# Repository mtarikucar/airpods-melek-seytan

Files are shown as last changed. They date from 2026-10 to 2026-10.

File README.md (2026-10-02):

# AirPods melek ve şeytan

Kulaklık sapına geçen melek (sağ kulaklık) ve şeytan (sol kulaklık) figürleri. Dört kulaklık grubu için basılabilir STL dosyaları **[out/](out/OKU_BENI.md)** klasöründedir: AirPods 4/5, AirPods Pro 3, AirPods Pro 2 ve AirPods 2/1.

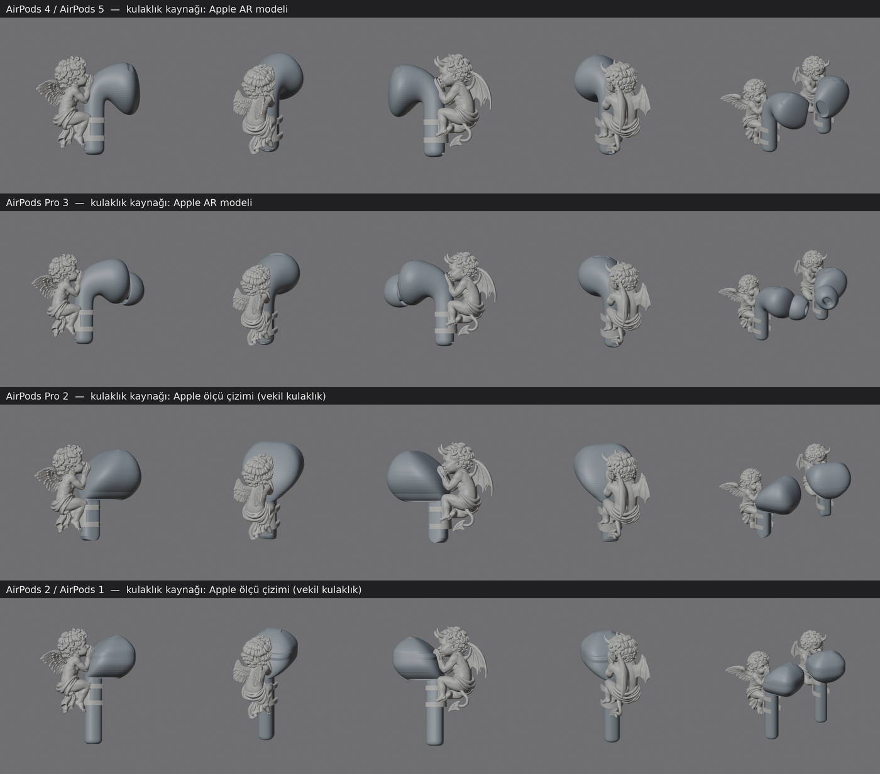
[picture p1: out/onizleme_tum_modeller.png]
Tüm modeller


Baskı, geçme testi ve kullanım uyarıları [out/OKU_BENI.md](out/OKU_BENI.md) dosyasındadır.

## Site ilanı

Ürün sayfası için görseller ve Türkçe metin **[out/ilan/](out/ilan/ILAN_METNI.md)** klasöründedir: `gorseller/` altında 11 JPG (melek beyaz, şeytan kırmızı), `ILAN_METNI.md` içinde ürün adı, açıklamalar, SSS, SEO alanları ve alt metinler.

Görseller satışa hazır STL'lerden Cycles ile çizilen render'lardır, fotoğraf değildir. Yeniden üretmek için:

1. `blender -b --factory-startup --python scripts/ilan_render.py` (ham render'lar `work/ilan/` altına; `--preview` hızlı ve küçük, `--shots ana,melek` tek tek çizer)
2. `.venv/bin/python scripts/ilan_etiket.py` (yazıları ve ölçü çizgilerini ekler, `out/ilan/gorseller/` altına JPG yazar)

Renkler `ilan_render.py` başındaki `MELEK_COL` ve `SEYTAN_COL` değerleridir.

## Tanıtım videoları

**[videolar/](videolar/)** klasöründe iki tanıtım videosu, her biri 4K ve 1080p olarak:

| Dosya | Çözünürlük | Süre |
|---|---|---|
| `urun_videosu_dikey_4k.mp4` | 2160×3840 (dikey) | 8 sn |
| `urun_videosu_dikey_1080p.mp4` | 1080×1920 (dikey) | 8 sn |
| `kisa_film_4k.mp4` | 3840×2160 | 24 sn |
| `kisa_film_1080p.mp4` | 1920×1080 | 24 sn |

Videolar yapay zekâ ile üretildi (Seedance 2.5, 480p/612p taslak), sonra SeedVR2 7B ile yerelde 1080p ve 4K'ya büyütüldü. `kisa_film_4k.mp4` GitHub'ın 100 MB dosya sınırına sığması için daha düşük bit hızıyla kodlandı.

## Kaynaklar

- `references/`: kullanıcının verdiği konsept görselleri. Figürler `kaynak_figurler.png` görselinden kırpılan `melek.png` ve `seytan.png` ile üretildi.
- Figürler Meshy image-to-3d ile üretildi (meshy-7.1, 4k geometri, doku yok). İki üretim toplam 50 kredi harcadı; kalan bakiye 2385. API anahtarı hiçbir dosyaya yazılmadı, yalnızca `MESHY_API_KEY` ortam değişkeninden okunur.
- Kulaklık geometrisi:
  - AirPods 5 (4 ile aynı gövde) ve Pro 3: apple.com ürün sayfalarındaki AR (USDZ) modeller.
  - Pro 2 ve AirPods 2: developer.apple.com/accessories/dimensional-drawings çizimleri.
  
  Ham dosyalar `raw/` altında yerelde tutulur.

## Yeniden üretim

Kurulum: `python -m venv .venv && .venv/bin/pip install -r requirements.txt`. Blender 5.2 kullanıldı.

1. `python scripts/crop_refs.py`: kaynak görselden figürleri kırpar.
2. `MESHY_API_KEY=... python scripts/meshy.py submit melek seytan` ve `... wait melek seytan`: üretir ve `raw/<figür>/` altına indirir.
3. `blender -b --python scripts/solidify_figure.py -- raw/<figür>/stl.stl work/<figür>_solid.stl`, ardından `python scripts/decimate.py work/<figür>_solid.stl work/<figür>_600k.stl 600000`: figürü 30 mm, kapalı katı yapar.
4. Kulaklıkları hazırlar:
   - `blender -b --python scripts/extract_earbud.py -- raw/airpods5.usdz earbuds/airpods45` (aynısı `airpodspro3.usdz` için de), ardından `decimate.py ... earbuds/<ad>_{L,R}_dec.stl 250000`.
   - `python scripts/make_proxy.py`: Pro 2 ve AirPods 2'yi çizimlerden kurar. Sonra `scripts/voxel_clean.py` ve `decimate.py` çalıştırılır.
5. `scripts/run_all.sh`: dört modeli üretir (`build.py`), kuponları çıkarır (`coupons.py`), et kalınlığını ölçer (`check_thickness.py`), paketi ve önizlemeleri hazırlar (`package.py`).

## Geçme tasarımı (`scripts/build.py`)

- Kişi -Y yönüne bakar, +Z yukarıdır. Sağ kulaklık -X tarafındadır.
- Figür sapın arkasına (+Y) yerleşir, dizleri sapa 2,5 mm gömülür, 1,5 mm dışa kaydırılır.
- Figürden, kulaklığın önden arkaya takılırken süpürdüğü hacim çıkarılır; bu yüzden takmayı engelleyen alttan kesik kalmaz.
- Kulaklık ile figür arasında yan başına 0,12 mm boşluk vardır.
- Diz ve ayak hizasında 1,8 mm yüksek, 1,1 mm kalın iki C kelepçe vardır. Ağızları sapın X genişliğinin %84'üdür.
- Sapın arkasındaki 1,0 mm şerit kelepçeleri figüre bağlar.
- Ellerin altında, kulaklık başına 1,0 mm oturan avuç yastığı vardır. Bu yastık ellerin dışbükey zarfıyla sınırlıdır.
- Başa bakan kanat kesilir.
- Dışa aktarmada aynı konumdaki köşeler birleştirilir ve 0,002 mm altı kıymıklar temizlenir (`fitlib.clean_export`).

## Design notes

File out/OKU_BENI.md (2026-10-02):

# AirPods melek ve şeytan figürleri

Melek **sağ**, şeytan **sol** kulaklığa takılır. Figür sapın arka tarafından yukarı tırmanmış durur, ellerini kulaklığın başına dayar. Sapı diz ve ayak hizasındaki iki C kelepçe sarar; avuçlar kulaklık başının arka yüzüne oturur. Figür kulaklığa arkadan, ileri doğru bastırılarak takılır; kelepçeler sapın üzerinden esneyip geçerek oturacak şekilde tasarlandı.

Tüm modeller

## Modeller

| Klasör | Uyduğu kulaklık | Figür boyu | Ağırlık (1,15 g/cm³) | Kulaklık geometrisinin kaynağı |
|---|---|---|---|---|
| `airpods45/` | AirPods 4, AirPods 5 | 30 mm | melek 1,67 g, şeytan 1,85 g | Apple'ın AR modeli (gerçek ölçekli 3B) |
| `airpodspro3/` | AirPods Pro 3 | 30 mm | 1,67 g / 1,86 g | Apple'ın AR modeli |
| `airpodspro2/` | AirPods Pro 2 (Lightning ve USB-C) | 30 mm | 1,67 g / 1,85 g | Apple ölçü çizimi, vekil kulaklık |
| `airpods2/` | AirPods 2, AirPods 1 | 32 mm | 2,01 g / 2,23 g | Apple ölçü çizimi, vekil kulaklık |

Apple'ın çizimine göre AirPods 4 ve AirPods 5'in gövdesi aynıdır. AirPods 3'ün gövdesi farklı olduğu için pakette yoktur, istenirse eklenir. Taklit AirPods'ların ölçüleri değiştiği için onlara uyum garanti değildir.

## Dosyalar (her model klasöründe)

- `baski/melek_sag.stl`, `baski/seytan_sol.stl`: basılacak figürler. Tablanın ortasında, en alt noktası Z=0'da, takıldığı duruşta dik durur.
- `baski/gecme_testi_sag.stl`: üç geçme test kuponu (aşağıya bakın).
- `montaj/`: figürler ve kulaklık aynı koordinatlarda. `kulaklik_*_referans.stl` yalnızca önizleme ve kontrol içindir, **basılmaz**.
- `onizleme.png`: soldan sağa: melek (yandan, arkadan), şeytan (yandan, arkadan), ikisi birlikte.
- `kontrol/`: ölçüler, ağırlık, kulaklıkla çakışma hacmi (hepsinde 0) ve kulaklığa yakın bölgedeki et kalınlığı ölçümleri.

STL birimi milimetredir. İçe aktarırken %100 ölçek kullanın.

## Baskıdan önce: geçme testi

1. Seçtiğiniz kulaklığın `gecme_testi_sag.stl` dosyasını, üretimde kullanacağınız reçine, pozlama, yıkama ve kürleme ayarlarıyla basın.
2. Kuponların arka bloğundaki çentik sayısı kupon numarasıdır. Kupon 1'de yan başına 0,08 mm, kupon 2'de 0,12 mm, kupon 3'te 0,16 mm boşluk vardır. **Figürler 0,12 mm ile hazırlandı.**
3. Kuponu sağ kulaklığın sapına arkadan bastırın. Doğru kupon zorlanmadan "tık" diye oturmalı, sallanmamalı ve sap bükülmeden çıkabilmelidir.
4. Kupon 2 uymuyorsa hangisinin uyduğunu bildirin; figürler o boşlukla yeniden üretilir (`scripts/build.py` içindeki `CLEAR` değeri).
5. Pro 2 ve AirPods 2 kulaklık şekilleri çizimden kurulduğu için bu iki modelde test özellikle önemlidir.

## Baskı notları

- **Reçine:** Kelepçeler takıp çıkarırken esner. Standart reçine bu esnemede çatlayabilir, bu yüzden tough, ABS-like veya esnekliği artırılmış bir karışım önerilir. Kelepçe et kalınlığı 1,1 mm, arkadaki bağlantı şeridi 1,0 mm'dir.
- **Yön:** Figürün sırtını (kanat tarafını) tablaya bakacak şekilde 30–45° eğik koyun. Destekleri sırta, kanatların arkasına ve örtünün altına verin.
- **Desteksiz kalması gereken yüzeyler:** Kelepçelerin iç yüzü, sap oluğu, avuçların kulaklığa oturan yüzü ve yüz. Bu yüzeylerdeki destek izi geçmeyi bozar.
- Kanat tüyleri ve saç kıvrımları bu boyutta yaklaşık 0,3–0,5 mm incelikte. Yıkama ve destek sökme sırasında dikkatli olun.
- Boya ve astar kelepçe içine ve avuç yüzeyine birikmemelidir. Bu yüzeyler boşluğu daraltır.

## Kullanım ve uyarılar

- **Şarj kutusu:** Figür takılıyken kulaklık kutuya girmez. Kutuya koymadan önce figür çıkarılır.
- **Anten ve sensör bölgesi:** Apple'ın aksesuar çizimlerinde AirPods 4/5, Pro 2 ve Pro 3'ün sapının tamamı, AirPods 2'de ise sapın arka yüzü taralı bölgedir: "Bu bölgelere giren aksesuarlar ürün performansını olumsuz etkiler." Figür bu bölgeyi sarar. Bluetooth menzilinde düşüş, aramada mikrofon kalitesinde değişim ve sap üzerindeki sıkma/dokunma kontrollerinde zorluk olabilir. Prototip bir telefon görüşmesi ve menzil denemesiyle sınanmalıdır.
- Sapın altındaki şarj kontakları ve hoparlör açık kalır. AirPods 2'de başın arka yüzündeki mikrofon deliği figüre yakındır.
- **Ağırlık ve kulağa oturma:** Figür 4–5,5 g'lık kulaklığa 1,7–2,2 g ekler. Gerçek bir kulak modeliyle deneme yapılmadı. Figürün kulak kepçesine değip değmediği ve kulaklığın yerinde kalıp kalmadığı prototipte görülmelidir.
- Başa bakan (içteki) kanat, kafaya değmemesi için kesildi. Dışarıdan görünen profil görsellerdeki gibidir.
- Fiziksel baskı ve takma denemesi yapılmadı. Sayısal kontroller (su geçirmezlik, kulaklıkla sıfır çakışma, et kalınlığı) baskı denemesinin yerine geçmez.

## Pro 2 ve AirPods 2 hakkında

Bu iki modelin Apple'da 3B dosyası artık yayında değil. Kulaklıklar Apple'ın ölçü çizimlerindeki ön ve yan siluetlerden kuruldu:

- Sap kesiti ölçüldü: Pro 2 5,6 × 6,4 mm, AirPods 2 5,9 × 6,4 mm.
- Kulaklık başı bilerek gerçeğinden biraz büyük tutuldu. Figürün elleri başa sürtmez ama aralarında küçük bir boşluk kalabilir.
- Kelepçeler bu ölçülere göre olduğu için geçme testi şarttır.

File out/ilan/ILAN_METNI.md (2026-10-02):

# İlan metni: AirPods uyumlu melek ve şeytan figür seti

Aşağıdaki bölümler siteye olduğu gibi kopyalanabilir. Müşteriye "siz" diye hitap eder; görsellerdeki yazılar da aynı dildedir. Köşeli parantezli yerler (`[...]`) senin dolduracağın bilgilerdir. Görseller `gorseller/` klasöründedir; en alttaki "Yayınlamadan önce" bölümü siteye konmaz, sana nottur.

---

## Ürün adı

**Önerilen:** AirPods Uyumlu Melek & Şeytan Figür Seti (2'li)

Diğer seçenekler:

- Melek & Şeytan Kulaklık Figürü, AirPods Uyumlu 2'li Set
- Omzundaki Melek ve Şeytan: AirPods Uyumlu Figür Seti

## Kısa açıklama

Sağ omzunuzdaki melek ile sol omzunuzdaki şeytan artık kulaklığınızda. AirPods sapına geçen, reçineden basılmış 30 mm'lik iki figür: melek sağ kulaklığa, şeytan sol kulaklığa.

## Uzun açıklama

Çizgi filmlerden bildiğiniz sahne: bir omuzda melek, diğerinde şeytan, ikisi de kulağınıza bir şeyler fısıldıyor. Bu set o sahneyi kulaklığınıza taşıyor.

Melek sağ kulaklığın, şeytan sol kulaklığın sapına arkadan tutunur. İkisi de sapa tırmanmış, ellerini kulaklığa dayamış, fısıldar gibi durur. Yandan bakıldığında melek ve şeytan birbirine dönüktür.

Figürler yüksek çözünürlüklü reçine baskıyla üretilir. Meleğin kıvırcık saçları, tüylü kanadı ve örtüsü; şeytanın boynuzları, sivri kulağı, yarasa kanadı ve ok uçlu kuyruğu 30 mm'lik gövdede tek tek seçilir.

Takmak için yapıştırıcı gerekmez. Her figürün arkasında, kulaklık sapını kavrayan iki küçük kelepçe vardır. Figürü sapın arkasına hizalayıp öne doğru bastırmanız yeterli; çıkarmak için geriye doğru çekersiniz.

Set, bir melek (beyaz) ve bir şeytan (kırmızı) figüründen oluşur. Kulaklık ve şarj kutusu sete dahil değildir.

*Görseller ürünün 3B modelinden hazırlanmıştır. Her figür tek tek basılıp elde temizlendiği için yüzeyde ve renk tonunda küçük farklar olabilir.*

## Öne çıkan özellikler

- 2'li set: melek sağ kulaklık için, şeytan sol kulaklık için
- Reçine 3B baskı, 30 mm boy
- Yapıştırıcısız: iki kelepçeyle sapa geçer, istediğinizde çıkarılır
- Figür başına yaklaşık 2 g
- Dört AirPods grubu için ayrı ölçüde üretilir: AirPods 4 / 5, Pro 3, Pro 2, AirPods 2 / 1
- Melek beyaz, şeytan kırmızı

## Teknik bilgiler

| | |
|---|---|
| İçerik | 1 melek (sağ kulaklık), 1 şeytan (sol kulaklık) |
| Malzeme | [reçine türü, ör. ABS benzeri dayanıklı reçine] |
| Üretim | Reçine (MSLA) 3B baskı, elde temizlenir |
| Boy | 30 mm (AirPods 2 / 1 modeli: 32 mm) |
| Genişlik × derinlik | yaklaşık 17 × 22 mm |
| Ağırlık | melek yaklaşık 1,7 g, şeytan yaklaşık 1,9 g (AirPods 2 / 1 modeli: 2,0 g ve 2,2 g) |
| Renk | Melek beyaz, şeytan kırmızı |
| Takma şekli | Sapı kavrayan iki kelepçe, yapıştırıcısız |

## Model seçimi

Figürler her kulaklığın sap ölçüsüne göre ayrı üretilir. Sipariş verirken kendi kulaklığınızı seçin:

| Seçenek | Uyduğu kulaklıklar |
|---|---|
| AirPods 4 / 5 | AirPods 4, AirPods 5 |
| AirPods Pro 3 | AirPods Pro 3 |
| AirPods Pro 2 | AirPods Pro 2 (Lightning ve USB-C) |
| AirPods 2 / 1 | AirPods 2, AirPods 1 |

- AirPods 3 için model yoktur.
- Muadil ve taklit kulaklıkların sap ölçüleri farklı olduğu için uyum garanti edilmez.
- Modelinizi bilmiyorsanız iPhone'da Ayarlar > Bluetooth'a girip kulaklığınızın yanındaki ⓘ simgesine dokunun; model adı orada yazar.

## Nasıl takılır

1. Meleği sağ kulaklığın, şeytanı sol kulaklığın sapının arkasına hizalayın.
2. Figürü öne, kulaklığa doğru bastırın.
3. Kelepçeler sapı kavrayıp figür yerine oturana kadar itin.

Çıkarmak için kulaklığı sapından tutup figürü geriye doğru çekin. Zorlamadan, düz bir hareketle çıkarın.

## Bilmeniz gerekenler

- **Şarj kutusu:** Figür takılıyken kulaklık şarj kutusuna girmez. Kutuya koymadan önce figürü çıkarın.
- **Bağlantı ve kontroller:** Figür kulaklığın sapını sarar. Sap, AirPods'ta antenin ve dokunma/sıkma kontrolünün bulunduğu bölgedir. Bluetooth menzili, aramalarda mikrofon ve sap üzerindeki kontroller figür takılıyken etkilenebilir. Bu ürün dekoratif bir aksesuardır.
- **Kırılgan detaylar:** Kanat uçları, boynuzlar ve kuyruk incedir. Figürü düşürmeyin, takılıyken cebe ya da çantaya atmayın.
- **Küçük parça:** 3 yaşından küçük çocuklar için uygun değildir, yutma tehlikesi vardır.
- **Isı ve güneş:** Reçine uzun süre doğrudan güneşte ve sıcak araç içinde bırakılmamalıdır.
- Bu ürün bağımsız bir aksesuardır. Apple Inc. tarafından üretilmemiştir ve onaylanmamıştır. AirPods, Apple Inc.'in tescilli markasıdır.

## Bakım

Kuru ya da hafif nemli yumuşak bir bezle silin. Aseton, tiner ve benzeri çözücüler kullanmayın. Suya daldırmayın.

## Sık sorulan sorular

**Hangi modeli seçmeliyim?**
Kulaklığınızın adına göre seçin: AirPods 4 / 5, AirPods Pro 3, AirPods Pro 2 ya da AirPods 2 / 1. Emin değilseniz sipariş notuna kulaklığınızın modelini yazın, biz kontrol edelim.

**Figür takılıyken kulaklık şarj kutusuna girer mi?**
Hayır. Kutuya koymadan önce figürü çıkarmanız gerekir.

**Sesi ya da bağlantıyı etkiler mi?**
Figür hoparlörü kapatmaz. Ancak sapı sardığı için Bluetooth menzili, arama sırasındaki mikrofon ve sap kontrolleri etkilenebilir.

**Yapıştırıcı gerekiyor mu?**
Hayır. Figür iki kelepçeyle sapa tutunur, istediğinizde çıkarılır.

**Spor yaparken kullanılır mı?**
Önermiyoruz. Figür dekoratif kullanım için tasarlandı; koşu ve spor gibi hareketli kullanımda düşebilir ya da kırılabilir.

**Kulaklık sete dahil mi?**
Hayır. Set yalnızca melek ve şeytan figüründen oluşur.

---

## SEO alanları

| Alan | Metin |
|---|---|
| Sayfa başlığı | AirPods Uyumlu Melek & Şeytan Figür Seti \| [Mağaza adı] |
| Meta açıklama | AirPods sapına geçen melek ve şeytan figürleri. Reçine baskı, 30 mm, 2'li set. AirPods 4/5, Pro 3, Pro 2 ve 2/1 için ayrı modeller. |
| URL | `/airpods-uyumlu-melek-seytan-figur-seti` |
| Anahtar kelimeler | airpods aksesuar, airpods süsü, airpods figür, kulaklık süsü, kulaklık figürü, melek şeytan figür, airpods pro aksesuar, reçine figür, 3d baskı figür, hediye |

## Görseller ve alt metinleri

| Dosya | Kullanım | Alt metin |
|---|---|---|
| `01_ana_gorsel.jpg` | Ana ürün görseli | Kulaklık saplarına takılı beyaz melek ve kırmızı şeytan figürleri, karşı karşıya |
| `02_melek_sag_kulaklik.jpg` | Galeri | Sağ kulaklığın sapına tutunmuş beyaz melek figürü |
| `03_seytan_sol_kulaklik.jpg` | Galeri | Sol kulaklığın sapına tutunmuş kırmızı şeytan figürü |
| `04_arkadan_gorunum.jpg` | Galeri | Melek ve şeytan figürlerinin arkadan görünümü, kanatlar ve kuyruk |
| `05_detay_melek.jpg` | Galeri | Melek figürünün yüzü, kıvırcık saçları ve kanadı yakından |
| `06_detay_seytan.jpg` | Galeri | Şeytan figürünün boynuzları, yüzü ve yarasa kanadı yakından |
| `07_figurler_kulakliksiz.jpg` | Galeri, "kutu içeriği" | Kulaklıksız melek ve şeytan figürleri, arkalarındaki kelepçeler görünür |
| `08_olculer.jpg` | Galeri, teknik bilgiler | Melek figürünün ölçüleri: 30 mm boy, 22 mm derinlik, 17 mm genişlik |
| `09_uyumluluk.jpg` | Model seçimi | Dört kulaklık grubunda takılı melek figürü: AirPods 4 / 5, Pro 3, Pro 2, AirPods 2 / 1 |
| `10_nasil_takilir.jpg` | Nasıl takılır | Figürün kulaklık sapına üç adımda takılışı |
| `11_banner_koyu.jpg` | Ana sayfa bandı, sosyal medya (2560 × 1440) | Koyu zeminde kulaklıklara takılı melek ve şeytan figürleri |

Ürün görselleri 2000 × 2000 piksel JPG'dir.

## Sosyal medya metni

Sağ kulağında melek, sol kulağında şeytan. 😇😈
AirPods sapına geçen 30 mm'lik reçine figür seti. Yapıştırıcı yok, tak-çıkar kullanım.
AirPods 4 / 5, Pro 3, Pro 2 ve 2 / 1 için.

#airpods #airpodsaksesuar #3dbaskı #reçinebaskı #figür #melekveşeytan #elyapımı

---

## Yayınlamadan önce (siteye konmaz)

1. **Görseller render'dır, fotoğraf değildir.** Satışa hazır STL'lerin kendisinden çizildi, yani şekil gerçektir; ama ürün henüz basılmadı. Uzun açıklamadaki "3B modelinden hazırlanmıştır" cümlesini, gerçek baskı fotoğrafı koyana kadar silme.
2. **Geçme testi yapılmadan satışa açma.** Kelepçe boşluğu (0,12 mm) henüz fiziksel olarak denenmedi. AirPods Pro 2 ve AirPods 2 / 1 kulaklıkları çizimden kurulduğu için bu iki seçenekte risk daha yüksek. Denemediğin seçeneği kapalı tutabilirsin.
3. **"Bilmeniz gerekenler" bölümünü kısaltma.** Kutuya girmeme ve anten/kontrol notu iade ve şikâyetin önüne geçer. Apple, sap bölgesini aksesuarların girmemesi gereken alan olarak işaretliyor.
4. **Metinde bilerek yazılmayanlar:** "sesi etkilemez", "kulakta rahattır", "düşmez", "çizmez", "cilt dostu" gibi ifadeler denenmediği için yok. Prototipte denedikten sonra ekleyebilirsin.
5. **Doldurulacak yerler:** reçine türü, mağaza adı, fiyat, kargo ve iade koşulları, üretim süresi.
6. **Renk:** Şeytan render'da kırmızı reçine olarak çizildi. Boyayla üreteceksen ton farklı çıkabilir.
7. **`09_uyumluluk.jpg`:** AirPods 4 / 5 ve Pro 3 kulaklıkları Apple'ın gerçek ölçekli modelinden, Pro 2 ve AirPods 2 / 1 ise çizimden kurulan yaklaşık şekillerden çizildi. Pro 2'de silikon uç görünmez.
8. Görselleri yeniden üretmek için: `blender -b --factory-startup --python scripts/ilan_render.py` ve ardından `.venv/bin/python scripts/ilan_etiket.py`.

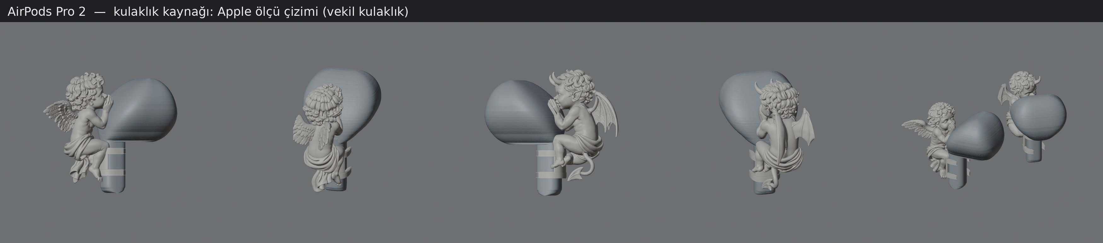
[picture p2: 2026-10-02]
out/airpodspro2/onizleme.png

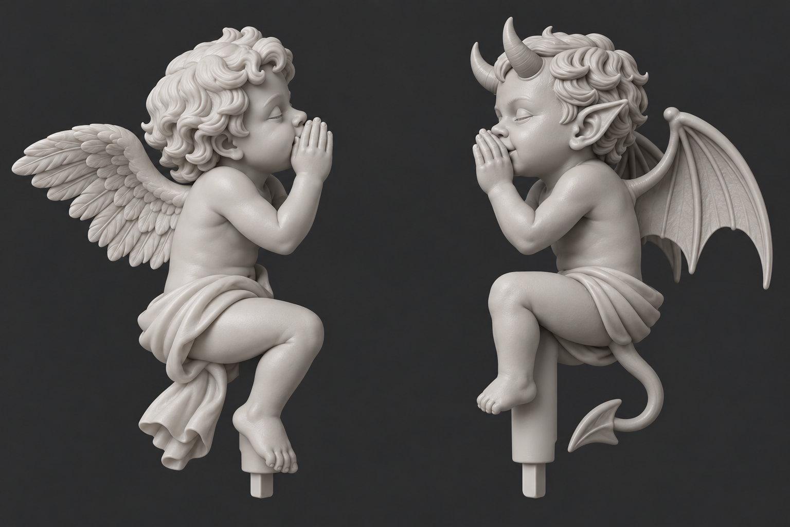
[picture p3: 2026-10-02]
references/pimli_konsept.png

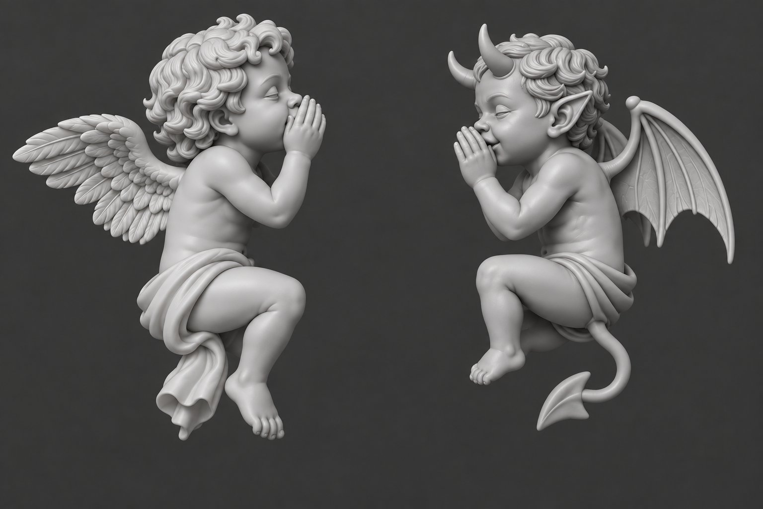
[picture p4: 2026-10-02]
references/kaynak_figurler.png

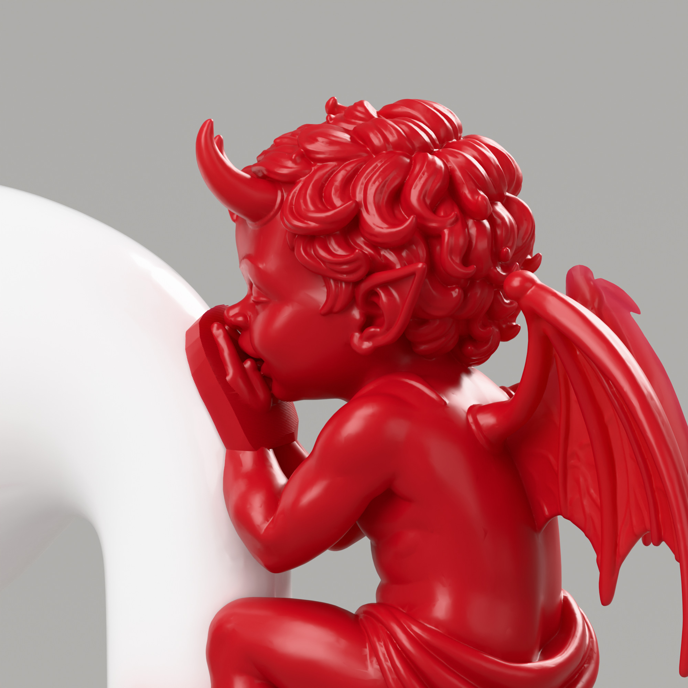
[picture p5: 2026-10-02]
out/ilan/gorseller/06_detay_seytan.jpg

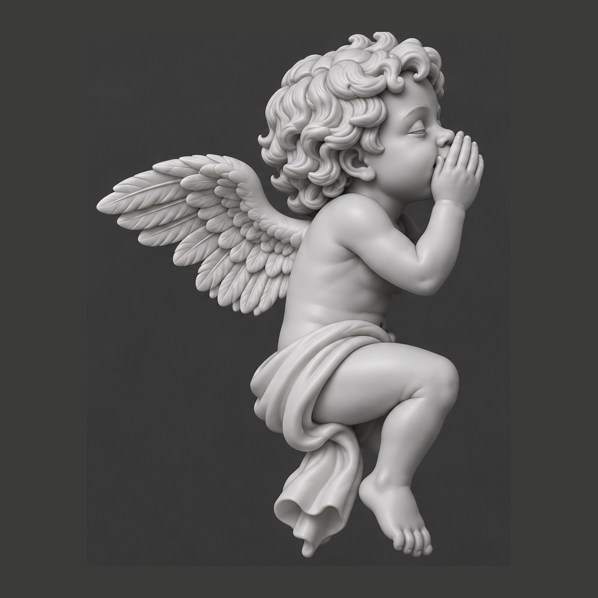
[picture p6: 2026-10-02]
references/melek.png

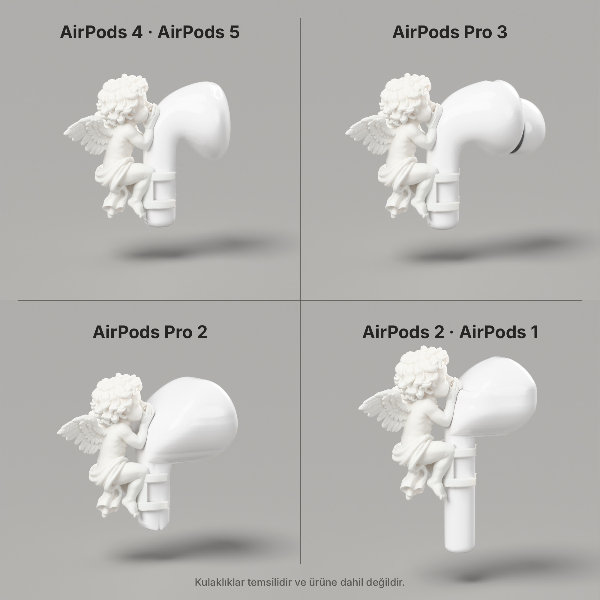
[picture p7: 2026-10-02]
out/ilan/gorseller/09_uyumluluk.jpg

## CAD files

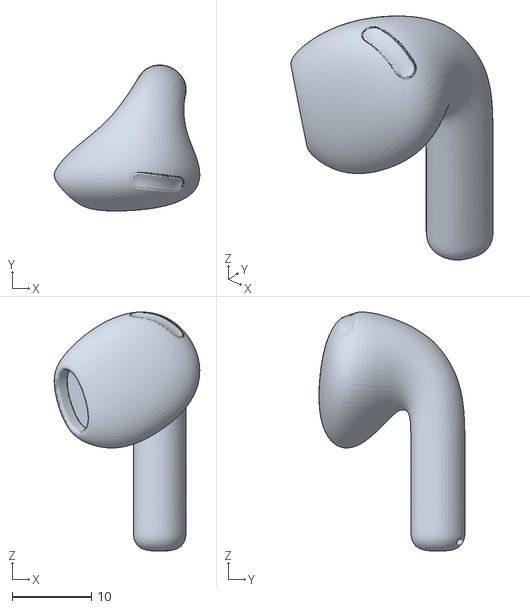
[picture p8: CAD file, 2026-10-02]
earbuds/airpods45_L_dec.stl
18.3 x 18.4 x 30.1

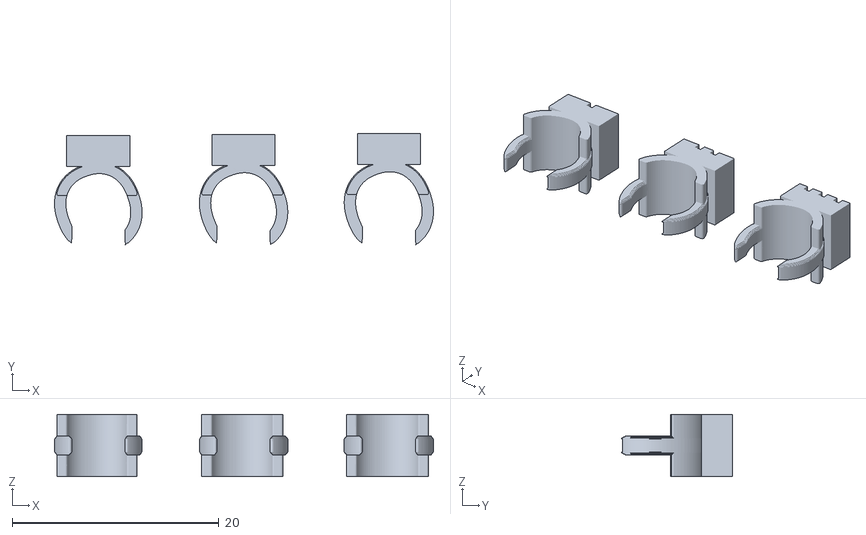
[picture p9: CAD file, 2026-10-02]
out/airpods2/baski/gecme_testi_sag.stl
36.6 x 10.7 x 6.00

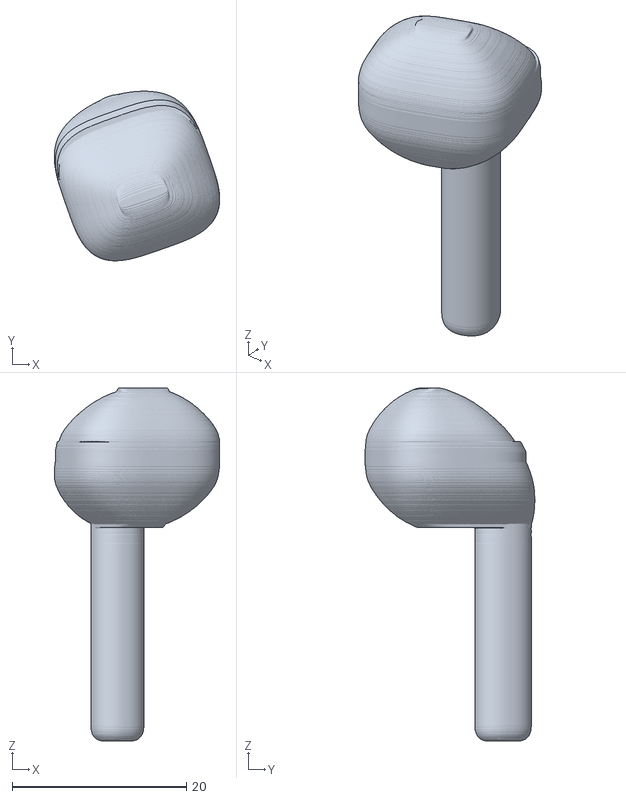
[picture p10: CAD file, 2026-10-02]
out/airpods2/montaj/kulaklik_sag_referans.stl
19.0 x 19.5 x 40.6

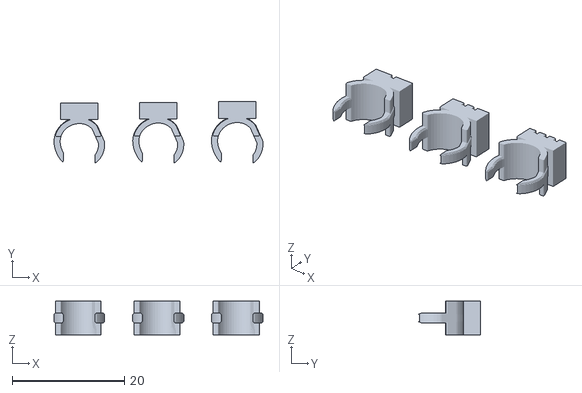
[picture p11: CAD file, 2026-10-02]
out/airpods45/baski/gecme_testi_sag.stl
37.2 x 10.9 x 6.00

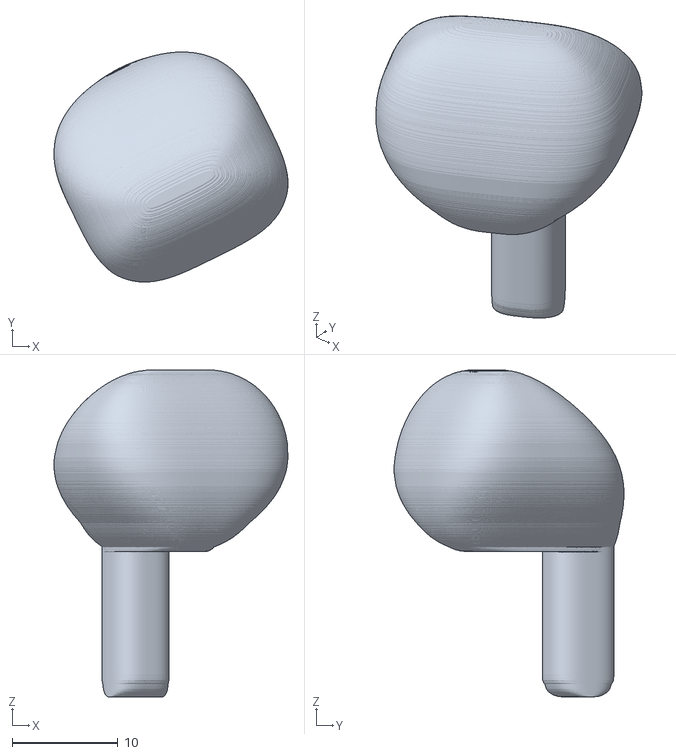
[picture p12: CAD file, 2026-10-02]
out/airpodspro2/montaj/kulaklik_sag_referans.stl
22.1 x 21.7 x 30.9

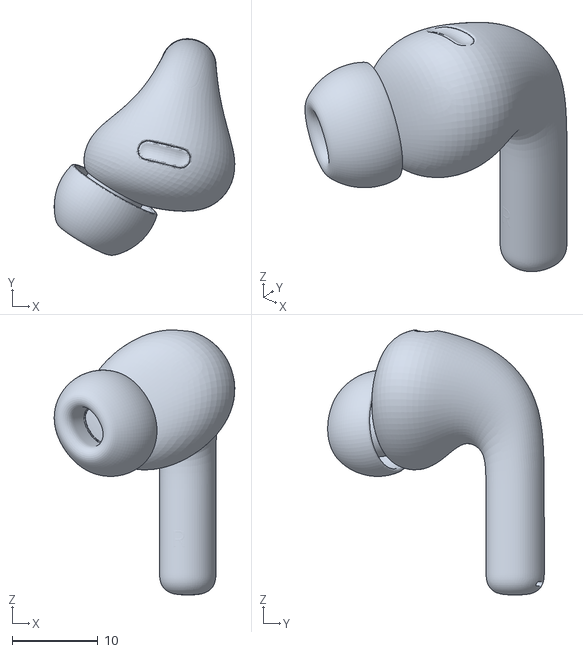
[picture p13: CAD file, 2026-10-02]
out/airpodspro3/montaj/kulaklik_sol_referans.stl
21.0 x 25.2 x 30.9

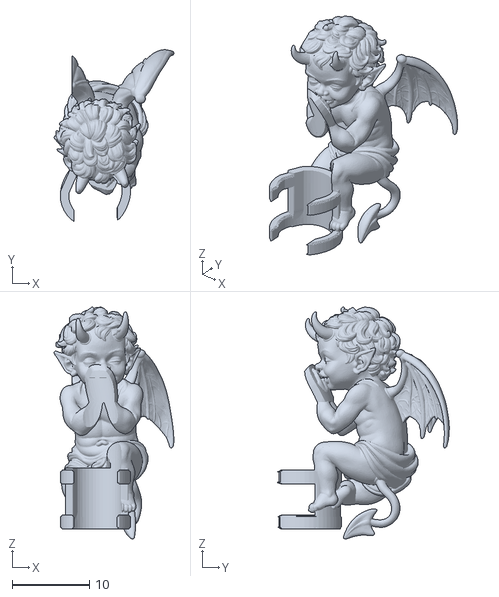
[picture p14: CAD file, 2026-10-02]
out/airpods45/baski/seytan_sol.stl
15.5 x 22.2 x 30.0

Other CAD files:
out/airpodspro2/baski/gecme_testi_sag.stl
out/airpodspro3/baski/gecme_testi_sag.stl
out/airpods2/montaj/kulaklik_sol_referans.stl
out/airpods45/montaj/kulaklik_sag_referans.stl
out/airpodspro2/montaj/kulaklik_sol_referans.stl
out/airpodspro3/montaj/kulaklik_sag_referans.stl
out/airpods45/montaj/seytan_sol.stl
earbuds/airpodspro3_R_dec.stl
earbuds/airpods2_L_dec.stl
earbuds/airpods45_R_dec.stl
earbuds/airpodspro2_L_dec.stl
